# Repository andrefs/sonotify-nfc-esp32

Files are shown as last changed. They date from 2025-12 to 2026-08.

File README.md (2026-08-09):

# sonotify-nfc-esp32

ESP32 firmware that reads NFC tags on an RC522 RFID module and triggers a Home Assistant webhook to play media on a Sonos speaker. NFC tag UIDs are mapped to media (Spotify tracks/playlists or Sonos favorites) through a JSON dispatch table.



## Features

- Reads NFC tag UIDs via an RC522 module over SPI
- Maps card UIDs to media items at boot through a `dispatch.json` table
- Fetches and refreshes `dispatch.json` from a web URL on every boot (optional), falling back to the copy stored in SPIFFS
- Triggers a Home Assistant webhook so Home Assistant can play the media item on a Sonos device
- Status LED communicates boot, Wi-Fi, and error states
- Prints unknown card UIDs so you can easily add tags to `dispatch.json`

## Repository layout

```
main/
  main.c            app_main boot sequence
  led.c/.h          status LED control
  wifi.c/.h         Wi-Fi STA connection (blocking, with retries)
  dispatch.c/.h     SPIFFS mount, dispatch.json load, web refresh, UID lookup
  ha_client.c/.h    Home Assistant webhook client
  rc522_scanner.c/.h  RC522 reader setup and card event handler
  Kconfig.projbuild  all configuration via menuconfig
data/
  dispatch.json     your local dispatch table (gitignored)
  dispatch.json.example  committed example table
tests/
    host-side unit tests for dispatch lookup (no hardware required)
.github/workflows/ci.yml  runs the tests on push/PR
```

## How it works

1. On boot: init LED, NVS, netif, event loop; connect to Wi-Fi.
2. Read `dispatch.json`:
   - If `DISPATCH_SOURCE_URL` is configured, fetch it (http or https), validate it, and store the fresh copy in SPIFFS.
   - On any failure (fetch or validation), fall back to the copy already stored in SPIFFS.
3. Start the RC522 scanner.
4. When a card is tapped: look up its UID in the dispatch table to get the media item, then POST `content_id`, `entity_id`, `content_type` to the Home Assistant webhook.

Unknown, unlisted cards print a message telling you exactly which `tagId` to add:

```
W (59967) rc522: Card not in dispatch.json. Add an entry with tagId "53 8C 96 B1 11 00 01" to add it
```

### Dispatch table format

A JSON array of entries, e.g. `data/dispatch.json`:

```json
[
  {
    "tagId": "04 AA BB CC DD EE FF",
    "contentId": "spotify:track:6sH1FvX2nqd7ZFMeKyi0cs",
    "description": "Ana Moura - Andorinhas",
    "contentType": "music"
  },
  {
    "tagId": "04 11 22 33 44 55 66",
    "contentId": "SQ:0",
    "description": "Sonos queue",
    "contentType": "favorite_item_id"
  }
]
```

- `tagId` — the space-separated hex UID printed by the reader firmware
- `contentId` — Spotify URI (`spotify:track:`…, `spotify:playlist:`…) or a Sonos queue/favorite reference (e.g. `SQ:0`)
- `contentType` — `music` (default) or `favorite_item_id`

The board expects `/spiffs/dispatch.json`; `data/dispatch.json` local copy is packed into SPIFFS at build time by ESP-IDF.

## Configuration

Run `idf.py menuconfig` and set:

**WiFi Configuration**
| Option | Description |
| --- | --- |
| `WIFI_SSID` | Wi-Fi SSID to join |
| `WIFI_PASSWORD` | Wi-Fi password |
| `WIFI_MAX_RETRY` | Connection attempts before giving up |

**Hardware Pin Configuration**
| Option | Description |
| --- | --- |
| `RC522_SPI_BUS_GPIO_MISO` | RC522 MISO (default 25) |
| `RC522_SPI_BUS_GPIO_MOSI` | RC522 MOSI (default 23) |
| `RC522_SPI_BUS_GPIO_SCLK` | RC522 SCLK (default 19) |
| `RC522_SPI_SCANNER_GPIO_SDA` | RC522 chip-select (default 22) |
| `RC522_SCANNER_GPIO_RST` | RC522 reset (default 21) |
| `RC522_SPI_CLOCK_HZ` | SPI clock (default 200000) |
| `LED_GPIO` | Status LED (default 32) |

**Media & Dispatch Configuration**
| Option | Description |
| --- | --- |
| `HA_WEBHOOK_URL` | Home Assistant webhook to trigger |
| `SONOS_ENTITY_ID` | Sonos media_player entity, e.g. `media_player.roam_2` |
| `DISPATCH_SOURCE_URL` | Optional URL to fetch `dispatch.json` from on boot (http/https); empty = use SPIFFS copy only |

## Build & flash

Hardware is a plain ESP32 with a 2 MB flash. Built and flashed with ESP-IDF:

```sh
idf.py menuconfig
idf.py build
idf.py -p /dev/ttyACM0 -b 115200 flash monitor
```

`idf.py menuconfig` writes your choices into the local `sdkconfig` (gitignored). `sdkconfig.defaults` ships placeholder Wi-Fi credentials (`changeme`); menus override it for each new build. `data/dispatch.json` is auto-packed into SPIFFS during build via the `spiffs` partition table entry.

## Tests

Host-side unit tests for the dispatch logic run without any dev board. Run them manually:

```sh
cmake -S tests -B build-tests
cmake --build build-tests
ctest --test-dir build-tests --output-on-failure
```

The GitHub Actions workflow performs the same steps on every push/PR to `main`.

## Troubleshooting

| Problem | Likely cause / fix |
| --- | --- |
| No LEDs / no boot-left logs | Check `-b 115200` and the USB serial device |
| "Failed to mount or format SPIFFS" | SPIFFS partition size; `data/` may not be flashable |
| Card UID printed but nothing plays | `tagId` missing/typo in `dispatch.json`, or webhook/entity misconfig |
| Internet fetch fails | `DISPATCH_SOURCE_URL` unreachable or invalid JSON; firmware falls back to SPIFFS copy |

## License

MIT
Copyright (c) 2026 André Santos

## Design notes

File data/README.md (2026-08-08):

# dispatch.json — your tag mapping (local, private)

`data/dispatch.json` is your **local** mapping of NFC tag UIDs to media items
that Home Assistant plays on a Sonos device via webhook. It is gitignored on
purpose, so your tags and Spotify URIs never end up in the repository.

A placeholder sample is committed as `data/dispatch.json.example`.

| Field | Description |
| --- | --- |
| `tagId` | NFC tag UID as printed by the RC522 firmware, e.g. `04 AA BB CC DD EE FF` |
| `contentId` | Spotify URI (`spotify:track:...`, `spotify:playlist:...`) or Sonos favorite (`SQ:0`) |
| `contentType` | `music` (default), or `favorite_item_id` for Sonos favorites |
| `description` | Human-readable label used in logs only |

Workflow:

1. Copy the example and fill in your own values:
   ```
   cp data/dispatch.json.example data/dispatch.json
   ```
2. Tap a card against the reader and read the printed UID from the serial
   monitor (or write the tag with an NFC tool). Put that value in `tagId`.
3. In the Spotify app copy the link of the track/playlist you want `contentId`
   to reference.
4. Keep one entry per card, ensuring `tagId` values are unique. Re-flash the
   SPIFFS image (`idf.py flash`) after editing.

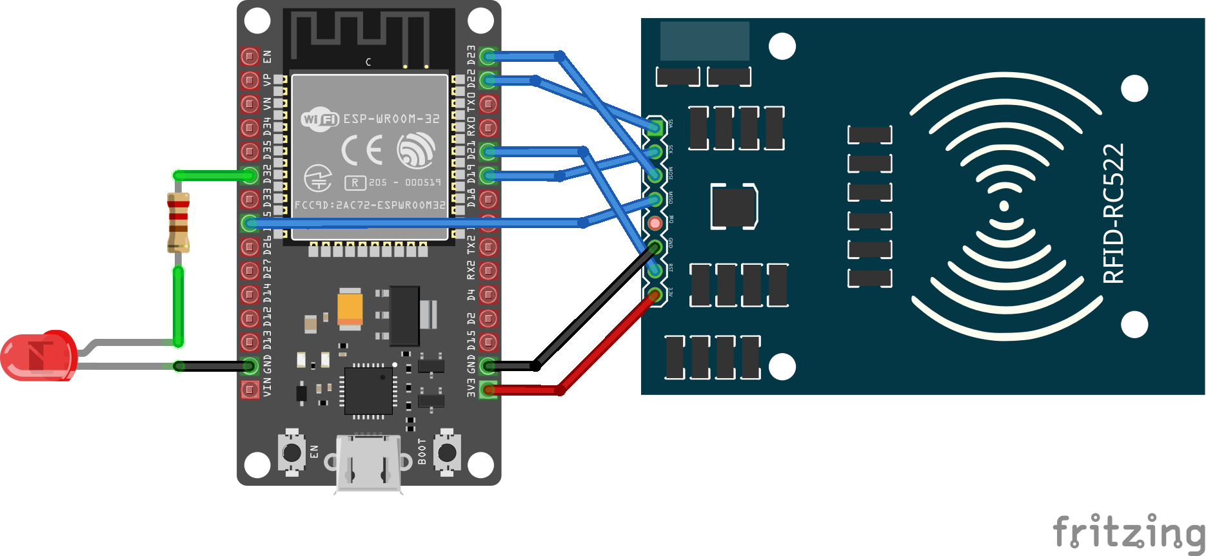
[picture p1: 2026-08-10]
schemas/sonotify_bb.png

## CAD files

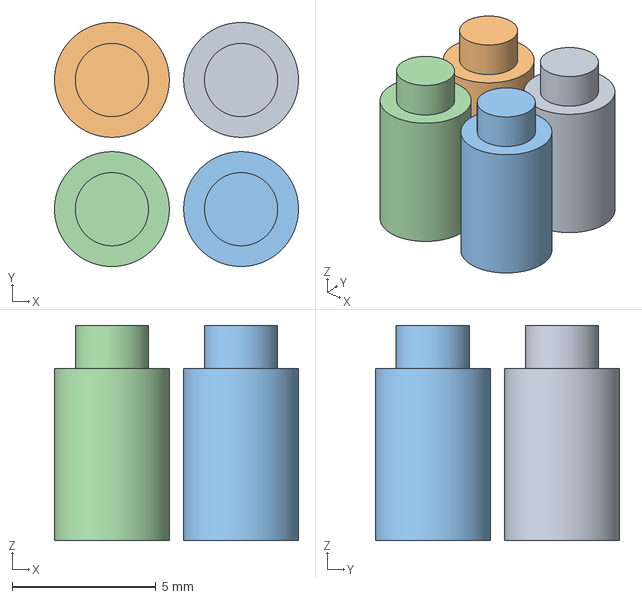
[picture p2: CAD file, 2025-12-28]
case/perfboard-risers.3mf
8.50 x 8.50 x 7.50 mm
Assembly x 4

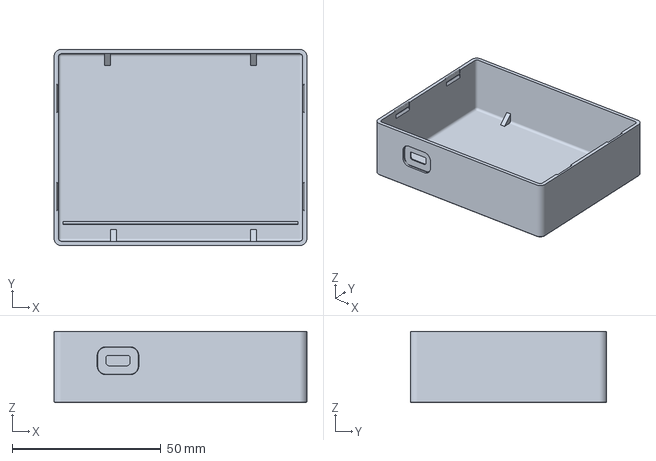
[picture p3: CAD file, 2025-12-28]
case/case-Body.3mf
85.0 x 66.0 x 24.0 mm

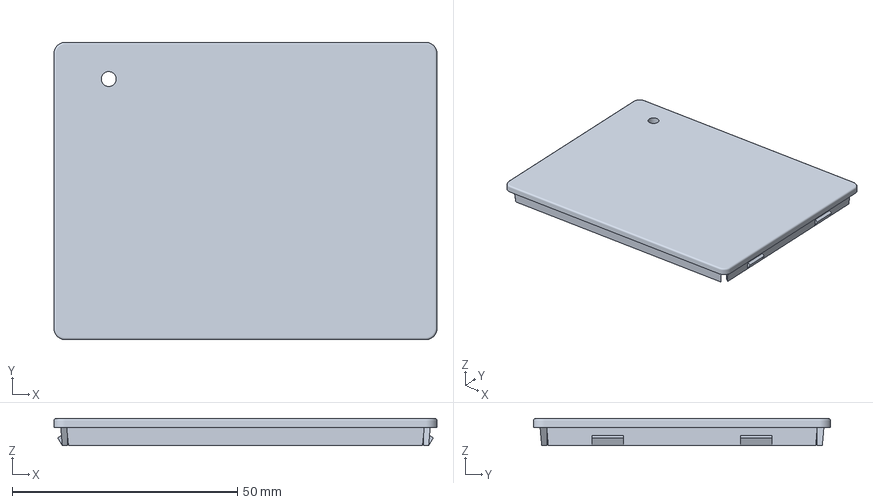
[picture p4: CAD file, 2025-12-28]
case/case-Lid.3mf
85.0 x 66.0 x 6.00 mm

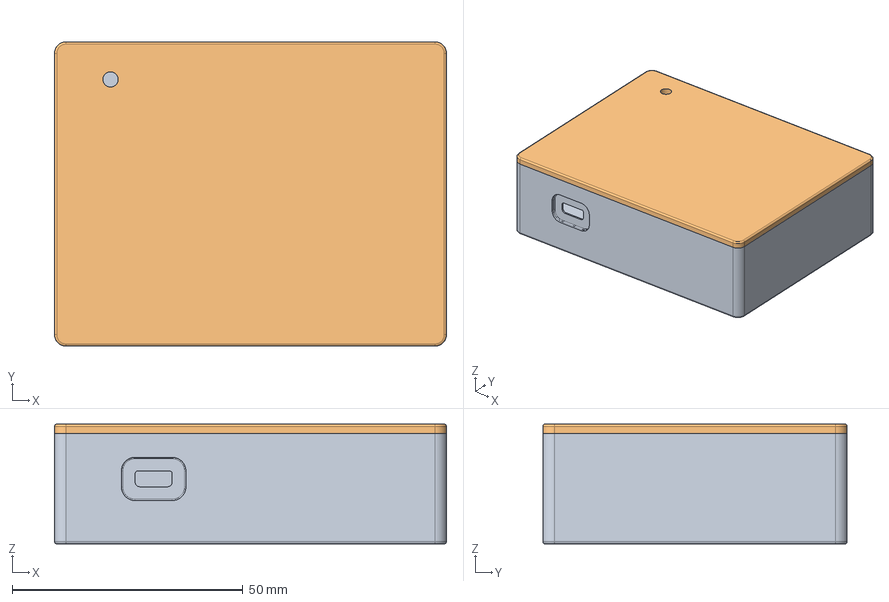
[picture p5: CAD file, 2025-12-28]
case/case.FCStd
85.0 x 66.0 x 26.0 mm
Case
Lid

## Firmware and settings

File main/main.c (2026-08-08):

#include "esp_err.h"
#include "esp_event.h"
#include "esp_log.h"
#include "esp_netif.h"
#include "freertos/FreeRTOS.h"

#include "nvs_flash.h"

#include "dispatch.h"
#include "led.h"
#include "rc522_scanner.h"
#include "wifi.h"

static const char *TAG = "main";

void app_main(void) {
  led_init();
  led_set(true); // LED ON while booting

  ESP_ERROR_CHECK(nvs_flash_init());
  ESP_ERROR_CHECK(esp_netif_init());
  ESP_ERROR_CHECK(esp_event_loop_create_default());

  wifi_init(); // blocks until connected/failed/timeout (up to 10 s)

  char *json = dispatch_load();
  if (!json) {
    ESP_LOGE(TAG, "Failed to read JSON file");
    return;
  }

  led_start_blink_task();

  esp_err_t ret = rc522_scanner_init(json);
  if (ret != ESP_OK) {
    ESP_LOGE(TAG, "Failed to start RC522 scanner: %s", esp_err_to_name(ret));
  }

  led_set(false); // LED OFF (blink task takes over if needed)
}

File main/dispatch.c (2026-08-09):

#include "dispatch.h"

#include <stdio.h>
#include <stdlib.h>
#include <string.h>

#include "cJSON.h"
#include "esp_crt_bundle.h"
#include "esp_http_client.h"
#include "esp_log.h"
#include "esp_spiffs.h"

static const char *TAG = "dispatch";

static bool init_spiffs(void) {
  esp_vfs_spiffs_conf_t conf = {.base_path = "/spiffs",
                                .partition_label = "spiffs",
                                .max_files = 5,
                                .format_if_mount_failed = true};

  esp_err_t ret = esp_vfs_spiffs_register(&conf);
  if (ret != ESP_OK) {
    if (ret == ESP_FAIL) {
      ESP_LOGE(TAG, "Failed to mount or format SPIFFS");
    } else if (ret == ESP_ERR_NOT_FOUND) {
      ESP_LOGE(TAG, "SPIFFS partition not found");
    } else {
      ESP_LOGE(TAG, "Failed to initialize SPIFFS (%s)", esp_err_to_name(ret));
    }
    return false;
  }

  size_t total = 0, used = 0;
  esp_err_t info_ret = esp_spiffs_info("spiffs", &total, &used);
  if (info_ret == ESP_OK) {
    ESP_LOGI(TAG, "SPIFFS total: %zu, used: %zu", total, used);
  } else {
    ESP_LOGW(TAG, "Failed to read SPIFFS info (%s)", esp_err_to_name(info_ret));
  }
  return true;
}

static char *read_json_file(const char *filename) {
  FILE *f = fopen(filename, "r");
  if (!f) {
    ESP_LOGE(TAG, "Failed to open file: %s", filename);
    return NULL;
  }

  fseek(f, 0, SEEK_END);
  long fsize = ftell(f);
  fseek(f, 0, SEEK_SET);

  char *json = malloc(fsize + 1);
  if (!json) {
    ESP_LOGE(TAG, "Out of memory");
    fclose(f);
    return NULL;
  }

  fread(json, 1, fsize, f);
  json[fsize] = '\0';
  fclose(f);

  ESP_LOGI(TAG, "Read JSON (%ld bytes): %s", fsize, json);
  return json;
}

static bool write_json_file(const char *filename, const char *json) {
  FILE *f = fopen(filename, "w");
  if (!f) {
    ESP_LOGE(TAG, "Failed to open file for writing: %s", filename);
    return false;
  }

  bool ok = fputs(json, f) >= 0;
  if (fclose(f) != 0) {
    ok = false;
  }
  return ok;
}

typedef struct {
  char *data;
  size_t len;
  size_t cap;
} http_body_t;

static esp_err_t http_event_handler(esp_http_client_event_t *event) {
  if (event->event_id != HTTP_EVENT_ON_DATA) {
    return ESP_OK;
  }
  http_body_t *body = (http_body_t *)event->user_data;
  size_t new_len = body->len + event->data_len;
  if (new_len >= body->cap) {
    size_t new_cap = body->cap ? body->cap * 2 : 256;
    while (new_cap < new_len) {
      new_cap *= 2;
    }
    char *new_data = realloc(body->data, new_cap + 1);
    if (!new_data) {
      ESP_LOGE(TAG, "Out of memory while reading HTTP body");
      return ESP_ERR_NO_MEM;
    }
    body->data = new_data;
    body->cap = new_cap;
  }
  memcpy(body->data + body->len, event->data, event->data_len);
  body->len = new_len;
  return ESP_OK;
}

static char *fetch_dispatch_json(const char *url) {
  http_body_t body = {0};
  esp_http_client_config_t config = {
      .url = url,
      .method = HTTP_METHOD_GET,
      .event_handler = http_event_handler,
      .user_data = &body,
      .crt_bundle_attach = esp_crt_bundle_attach,
      .timeout_ms = 5000,
  };

  esp_http_client_handle_t client = esp_http_client_init(&config);
  if (!client) {
    ESP_LOGE(TAG, "Failed to init HTTP client");
    return NULL;
  }

  esp_err_t err = esp_http_client_perform(client);
  int status = esp_http_client_get_status_code(client);
  esp_http_client_cleanup(client);

  if (err != ESP_OK || status != 200 || body.data == NULL) {
    ESP_LOGW(TAG, "GET %s failed: err=%s status=%d", url, esp_err_to_name(err),
             status);
    free(body.data);
    return NULL;
  }

  body.data[body.len] = '\0';
  ESP_LOGI(TAG, "Fetched JSON (%zu bytes): %s", body.len, body.data);
  return body.data;
}

static bool dispatch_sane(const char *json) {
  cJSON *root = cJSON_Parse(json);
  if (!root) {
    ESP_LOGE(TAG, "Fetched dispatch JSON failed to parse");
    return false;
  }

  if (!cJSON_IsArray(root) || cJSON_GetArraySize(root) == 0) {
    ESP_LOGE(TAG, "Fetched dispatch JSON is not a non-empty array");
    cJSON_Delete(root);
    return false;
  }

  cJSON *item;
  cJSON_ArrayForEach(item, root) {
    cJSON *tagId = cJSON_GetObjectItem(item, "tagId");
    cJSON *contentId = cJSON_GetObjectItem(item, "contentId");
    if (!cJSON_IsString(tagId) || !cJSON_IsString(contentId)) {
      ESP_LOGE(TAG, "Fetched dispatch JSON entry missing tagId/contentId");
      cJSON_Delete(root);
      return false;
    }
  }

  cJSON_Delete(root);
  return true;
}

char *dispatch_load(void) {
  if (!init_spiffs()) {
    return NULL;
  }

  const char *url = CONFIG_DISPATCH_SOURCE_URL;
  ESP_LOGI(TAG, "Dispatch JSON source URL: %s", url);
  if (url[0] != '\0') {
    char *fetched = fetch_dispatch_json(url);
    if (fetched != NULL) {
      if (dispatch_sane(fetched)) {
        if (write_json_file("/spiffs/dispatch.json", fetched)) {
          ESP_LOGI(TAG, "Dispatch JSON updated from %s", url);
          return fetched;
        }
        ESP_LOGW(TAG, "Failed to persist fetched dispatch JSON");
      } else {
        ESP_LOGW(TAG, "Fetched dispatch JSON failed sanity check");
      }
      free(fetched);
      ESP_LOGW(TAG, "Falling back to SPIFFS copy");
    } else {
      ESP_LOGW(TAG, "Failed to fetch dispatch JSON from %s, using SPIFFS",
               url);
    }
  }
  return read_json_file("/spiffs/dispatch.json");
}

static void copy_str(const char *src, char *dst, size_t dst_len) {
  if (!src) {
    dst[0] = '\0';
    return;
  }
  strncpy(dst, src, dst_len - 1);
  dst[dst_len - 1] = '\0';
}
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

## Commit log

2025-12-22 read data from local json file
    [partitions.csv]
2025-12-22 docs: add README for sonotify-nfc-esp32 project
2025-12-28 led on card
2025-12-28 3d case
    [case-Body.3mf, case-Lid.3mf, case.FCStd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]
2025-12-28 blink led on wifi connection and http error
2026-08-08 Step 1: remove secrets, move HA config to menuconfig, sanitize sample data
    - Replace hardcoded HA_WEBHOOK_URL and SONOS_ENTITY_ID with menuconfig options
    - Remove dead download_json() and stale JSON_URL
    - Sanitize dispatch.json sample data and ha-automation.yml (placeholders)
    - Add data/README explaining the dispatch schema
    - Document reliable flash baud (115200) in sdkconfig.defaults
    - Ignore secrets.txt used by history scrubbing
2026-08-08 Step 1 follow-up: keep dispatch.json local-only, commit an example instead
    - data/dispatch.json now gitignored (holds private tag UIDs / Spotify URIs)
    - data/dispatch.json.example carries the placeholder sample
    - data/README documents the copy-fill-flash workflow
2026-08-08 Step 2: move hardware pins, SPI clock, and retries to menuconfig
    - Add Hardware Pin Configuration menu (RC522 pins, SPI clock, LED GPIO)
    - Add WIFI_MAX_RETRY to the WiFi Configuration menu
    - Previously hardcoded values now come from CONFIG_* defaults
2026-08-08 Step 3: split monolithic main into modules
    - main.c: thin entry point; drop the 2s wifi wait hack
    - led, wifi, dispatch, ha_client, rc522_scanner modules with headers
    - remove file-global state (json/content_id/content_type); dispatch_lookup
    returns outputs through caller buffers
2026-08-08 fix: harden dispatch logging, SPIFFS info check, and RC522 start retry
    [dispatch.c, led.c, main.c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]
2026-08-09 fix: wire fetch event handler and log fetched dispatch JSON
    [dispatch.c]
2026-08-10 docs(schemas): add sonotify fritzing schema and breadboard image
    [sonotify.fzz]
